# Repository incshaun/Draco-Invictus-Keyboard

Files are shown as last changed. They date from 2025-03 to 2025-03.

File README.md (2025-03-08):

# Draco-Invictus-Keyboard
Converts wired keyboards into bluetooth keyboards

This project contains the software and hardware schematics for a device that allows older PS/2 style keyboards to appear as a bluetooth keyboard. The board uses an ESP32 system-on-chip microcontroller to provide the processing and bluetooth functionality, and requires some level converters to manage the 3.3V required by the ESP32 and 5V required by the PS/2 keyboard.

The software is largely derived from:
* https://github.com/T-vK/ESP32-BLE-Keyboard: for the bluetooth functionality.
* https://github.com/techpaul/PS2KeyAdvanced: for the PS/2 keyboard handling.
* https://github.com/ab0tj/PS2KeyAdvanced-Pico: for some fixes to PS/2 keyboard handling using ESP32
The licenses from these repositories applies to the corresponding code in this repository.

# Software

The software can be compiled and installed using the arduino IDE configured to support an ESP32 Dev Module.

The current version handles the standard keys, as well as capslock and numlock. Additional multimedia keys are not currently supported.

# Hardware

View of the completed board

Notes:
* Power to the unit is supplied using an USB connector. A powerbank is a suitable power source, and allows the keyboard to be portable.
* The ESP32 module is attached to an adapter board (e.g., https://www.komputer.de/zen/index.php?main_page=product_info&products_id=422). This provides buttons to reset and flash the software onto the chip. Note that pull-up resistors on the EN and IO0 lines are required and may not be present on the adapter board. Replacements ($10 \mathsf{k\Omega}$) are included in the schematic and board layout.
* External connector J1 is provided to attached an FTDI FT232RL USB Serial Converter module (e.g., https://littlebirdelectronics.com.au/products/ftdi-ft232rl-usb-to-ttl-serial-converter-adapter-module-5v-and-3-3v). Make sure that this is connected the right way around (GND pin should connect to the ground line), and that the voltage level is set to 3.3 V using the jumper on the board. This module can be removed once the software has been transferred.

The circuit diagram schematic:

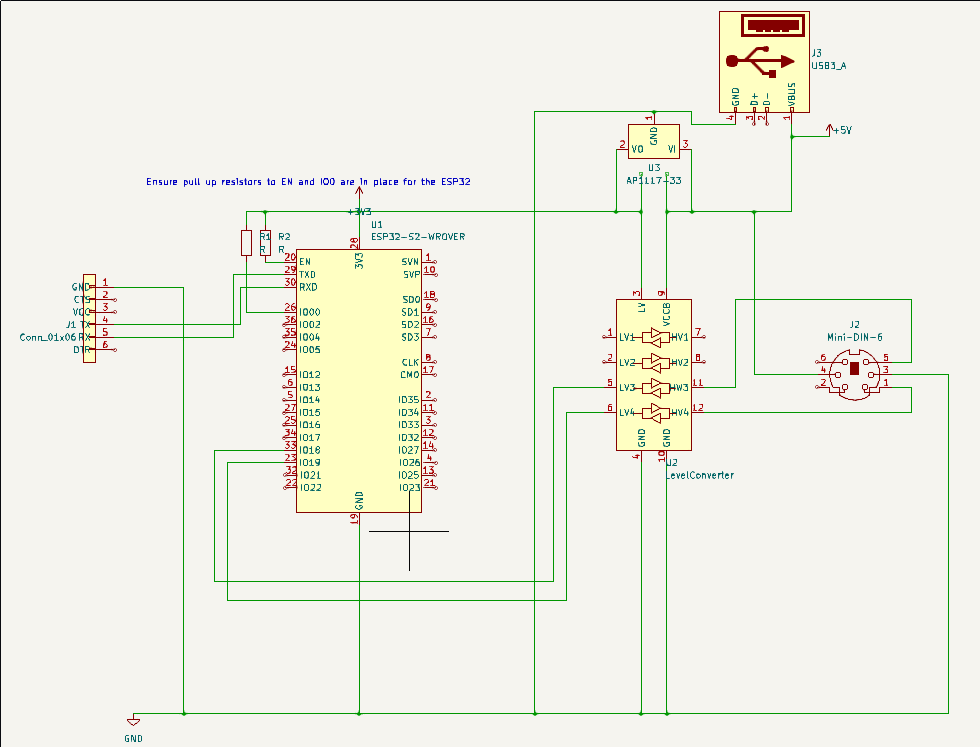
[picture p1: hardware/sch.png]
Schematic


The circuit board layout:

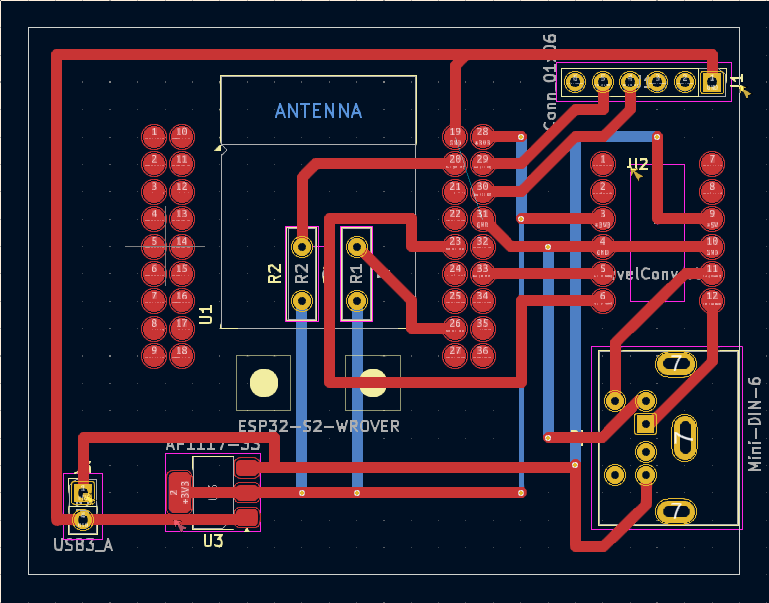
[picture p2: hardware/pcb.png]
Circuit board layout


## Views of an assembled board

Top:

Top View

Bottom (flipped to correspond with circuit layout):

Bottom View

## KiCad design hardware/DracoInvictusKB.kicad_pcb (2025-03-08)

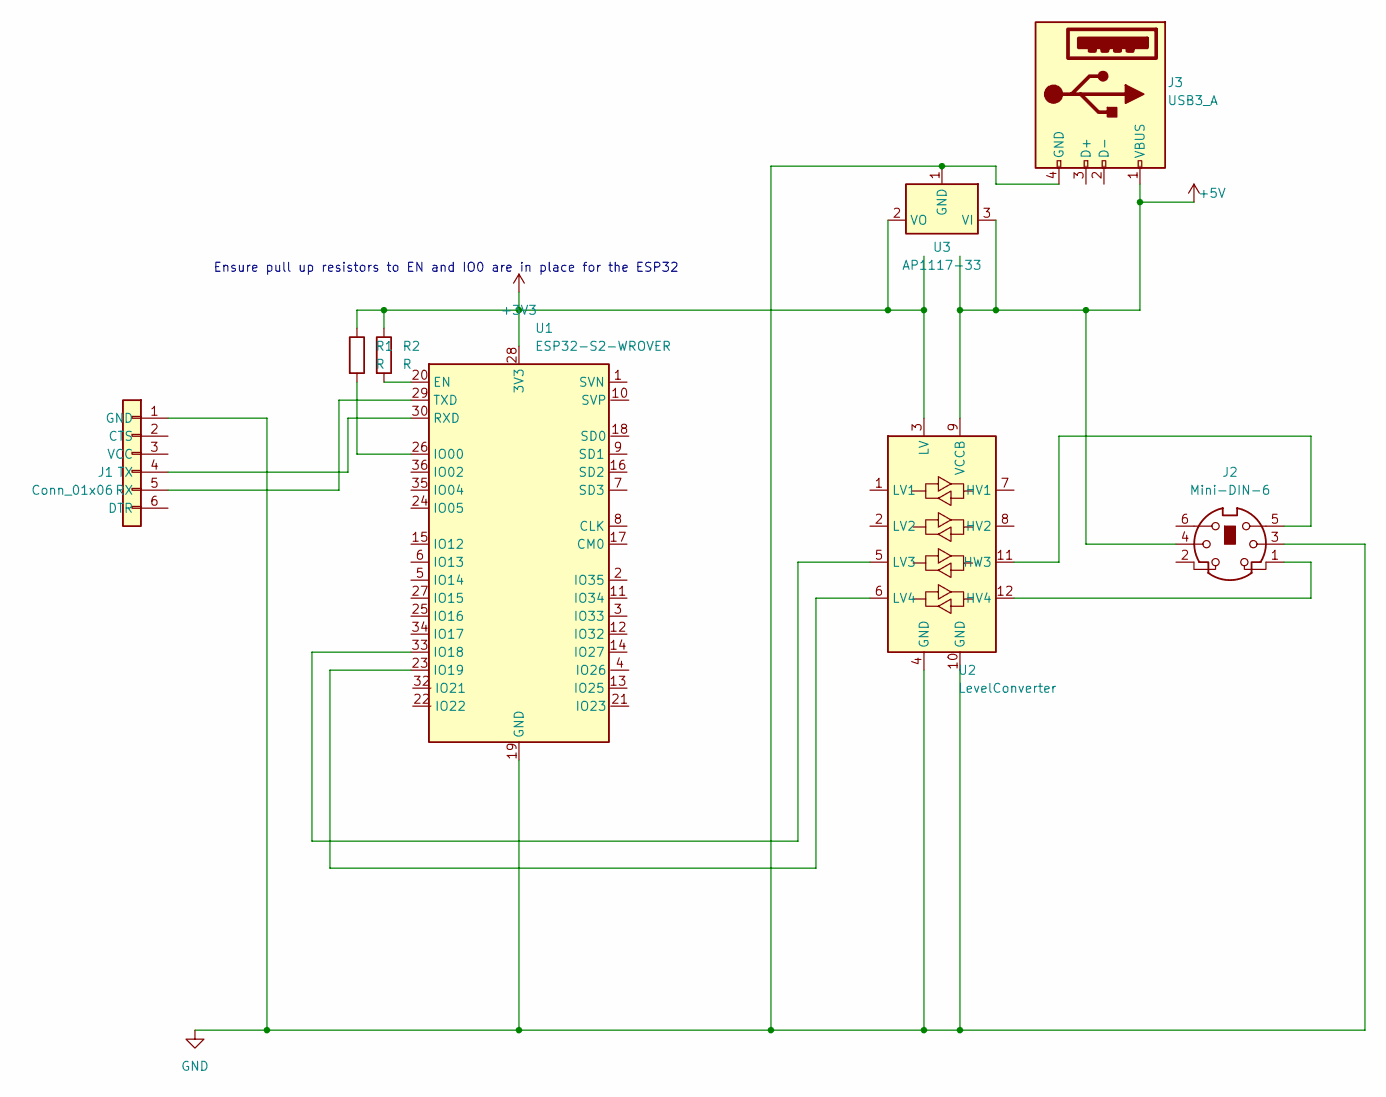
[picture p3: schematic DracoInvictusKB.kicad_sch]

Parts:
J1: Conn_01x06; PinHeader_1x06_P2.54mm_Vertical
J2: Mini-DIN-6; Connector_Mini-DIN_Female_6Pin_2rows
J3: USB3_A; PinHeader_1x02_P2.54mm_Vertical
R1, R2: R; R_Box_L8.4mm_W2.5mm_P5.08mm
U1: ESP32-S2-WROVER
U2: LevelConverter
U3: AP1117-33; SOT-223-3_TabPin2

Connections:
+3V3: R1.1, R2.1, U1.28 (3V3), U2.3 (LV), U3.2 (VO)
+5V: J2.4, J3.1 (VBUS), U2.9 (VCCB), U3.3 (VI)
GND: J1.1 (GND), J2.3, J3.4 (GND), U1.19 (GND), U1.31 (GND), U2.4 (GND), U2.10 (GND), U3.1 (GND)
unnamed: J1.5 (RX), U1.29 (TXD)
unnamed: J1.4 (TX), U1.30 (RXD)
unnamed: R2.2, U1.20 (EN)
unnamed: R1.2, U1.26 (IO00)
unnamed: U1.33 (IO18), U2.5 (LV3)
unnamed: U1.23 (IO19), U2.6 (LV4)
unnamed: J2.1, U2.12 (HV4)
unnamed: J2.5, U2.11 (HW3)

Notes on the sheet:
Ensure pull up resistors to EN and IO0 are in place for the ESP32

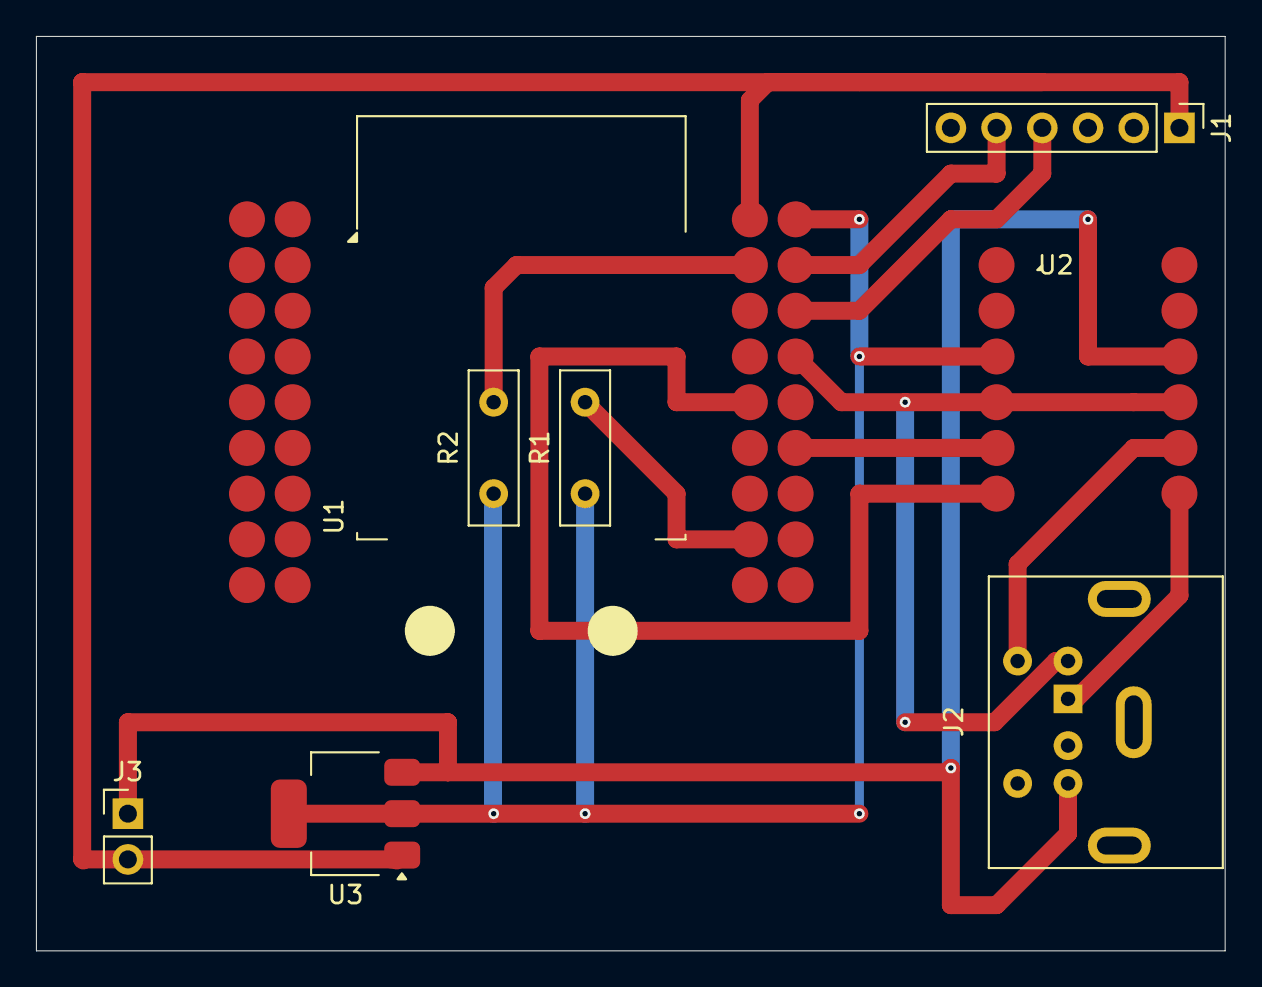
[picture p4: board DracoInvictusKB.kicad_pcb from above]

Board: 2 copper layers, 66.0 x 50.8 mm, 8 parts (0 on the bottom side), 11 nets.

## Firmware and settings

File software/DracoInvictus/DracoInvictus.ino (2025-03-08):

/**
 * This example turns the ESP32 into a Bluetooth LE keyboard that writes the words, presses Enter, presses a media key and then Ctrl+Alt+Delete
 */
#include "BleKeyboard.h"

BleKeyboard bleKeyboard("DracoInvictusKB");

#include "PS2KeyAdvanced.h"

#define DATAPIN 19
#define IRQPIN 18

uint16_t c;

PS2KeyAdvanced keyboard;


void setup() {
  Serial.begin(115200);

  keyboard.begin(DATAPIN, IRQPIN);
  Serial.println("PS2 Advanced Key Simple Test:");


  Serial.println("Starting BLE work!");
  bleKeyboard.begin();
}

void loop() {
  //  Serial.println ("Still alive");

  if (keyboard.available()) {
    // read the next key
    c = keyboard.read();
    if (c > 0) {
      Serial.print("Value ");
      Serial.print(c, HEX);
      Serial.print(" - Status Bits ");
      Serial.print(c >> 8, HEX);
      Serial.print("  Code ");
      Serial.println(c & 0xFF, HEX);


      if (bleKeyboard.isConnected()) {
        Serial.println("Sending");
        uint16_t key = c & 0xFF;

        switch (key) {
          case PS2_KEY_SPACE: key = ' '; break;
          case PS2_KEY_UP_ARROW: key = KEY_UP_ARROW; break;
          case PS2_KEY_DN_ARROW: key = KEY_DOWN_ARROW; break;
          case PS2_KEY_L_ARROW: key = KEY_LEFT_ARROW; break;
          case PS2_KEY_R_ARROW: key = KEY_RIGHT_ARROW; break;
          case PS2_KEY_BS: key = KEY_BACKSPACE; break;
          case PS2_KEY_TAB: key = KEY_TAB; break;
          case PS2_KEY_ENTER: key = KEY_RETURN; break;
          case PS2_KEY_ESC: key = KEY_ESC; break;
          case PS2_KEY_INSERT: key = KEY_INSERT; break;
          case PS2_KEY_PRTSCR: key = KEY_PRTSC; break;
          case PS2_KEY_DELETE: key = KEY_DELETE; break;
          case PS2_KEY_PGUP: key = KEY_PAGE_UP; break;
          case PS2_KEY_PGDN: key = KEY_PAGE_DOWN; break;
          case PS2_KEY_HOME: key = KEY_HOME; break;
          case PS2_KEY_END: key = KEY_END; break;

          case PS2_KEY_KP0: key = KEY_NUM_0; break;
          case PS2_KEY_KP1: key = KEY_NUM_1; break;
          case PS2_KEY_KP2: key = KEY_NUM_2; break;
          case PS2_KEY_KP3: key = KEY_NUM_3; break;
          case PS2_KEY_KP4: key = KEY_NUM_4; break;
          case PS2_KEY_KP5: key = KEY_NUM_5; break;
          case PS2_KEY_KP6: key = KEY_NUM_6; break;
          case PS2_KEY_KP7: key = KEY_NUM_7; break;
          case PS2_KEY_KP8: key = KEY_NUM_8; break;
          case PS2_KEY_KP9: key = KEY_NUM_9; break;
          case PS2_KEY_KP_DOT: key = KEY_NUM_PERIOD; break;
          case PS2_KEY_KP_ENTER: key = KEY_NUM_ENTER; break;
          case PS2_KEY_KP_PLUS: key = KEY_NUM_PLUS; break;
          case PS2_KEY_KP_MINUS: key = KEY_NUM_MINUS; break;
          case PS2_KEY_KP_TIMES: key = KEY_NUM_ASTERISK; break;
          case PS2_KEY_KP_DIV: key = KEY_NUM_SLASH; break;
          case PS2_KEY_KP_EQUAL: key = '='; break;
          case PS2_KEY_KP_COMMA: key = ','; break;

          case PS2_KEY_APOS: key = '\''; break;
          case PS2_KEY_COMMA: key = ','; break;
          case PS2_KEY_MINUS: key = '-'; break;
          case PS2_KEY_DOT: key = '.'; break;
          case PS2_KEY_DIV: key = '/'; break;
          case PS2_KEY_SINGLE: key = '`'; break;
          case PS2_KEY_SEMI: key = ';'; break;
          case PS2_KEY_BACK: key = '\\'; break;
          case PS2_KEY_OPEN_SQ: key = '['; break;
          case PS2_KEY_CLOSE_SQ: key = ']'; break;
          case PS2_KEY_EQUAL: key = '='; break;

          case PS2_KEY_F1: key = KEY_F1; break;
          case PS2_KEY_F2: key = KEY_F2; break;
          case PS2_KEY_F3: key = KEY_F3; break;
          case PS2_KEY_F4: key = KEY_F4; break;
          case PS2_KEY_F5: key = KEY_F5; break;
          case PS2_KEY_F6: key = KEY_F6; break;
          case PS2_KEY_F7: key = KEY_F7; break;
          case PS2_KEY_F8: key = KEY_F8; break;
          case PS2_KEY_F9: key = KEY_F9; break;
          case PS2_KEY_F10: key = KEY_F10; break;
          case PS2_KEY_F11: key = KEY_F11; break;
          case PS2_KEY_F12: key = KEY_F12; break;
          case PS2_KEY_F13: key = KEY_F13; break;
          case PS2_KEY_F14: key = KEY_F14; break;
          case PS2_KEY_F15: key = KEY_F15; break;
          case PS2_KEY_F16: key = KEY_F16; break;
          case PS2_KEY_F17: key = KEY_F17; break;
          case PS2_KEY_F18: key = KEY_F18; break;
          case PS2_KEY_F19: key = KEY_F19; break;
          case PS2_KEY_F20: key = KEY_F20; break;
          case PS2_KEY_F21: key = KEY_F21; break;
          case PS2_KEY_F22: key = KEY_F22; break;
          case PS2_KEY_F23: key = KEY_F23; break;
          case PS2_KEY_F24:
            key = KEY_F24;
            break;

          case PS2_KEY_NUM: key = KEY_NUM_LOCK; break;
          case PS2_KEY_SCROLL: key = KEY_SCROLL_LOCK; break;
          case PS2_KEY_CAPS:
            key = KEY_CAPS_LOCK;
            break;
            //          case PS2_KEY_PAUSE : key = KEY_; break;
          case PS2_KEY_L_SHIFT: key = KEY_LEFT_SHIFT; break;
          case PS2_KEY_R_SHIFT: key = KEY_RIGHT_SHIFT; break;
          case PS2_KEY_L_CTRL: key = KEY_LEFT_CTRL; break;
          case PS2_KEY_R_CTRL: key = KEY_RIGHT_CTRL; break;
          case PS2_KEY_L_ALT: key = KEY_LEFT_ALT; break;
          case PS2_KEY_R_ALT: key = KEY_RIGHT_ALT; break;
          case PS2_KEY_L_GUI: key = KEY_LEFT_GUI; break;
          case PS2_KEY_R_GUI:
            key = KEY_RIGHT_GUI;
            break;
            //          case PS2_KEY_MENU : key = KEY_; break;
            //          case PS2_KEY_BREAK : key = KEY_; break;
        }
        if ((key >= 'A') && (key <= 'Z')) {
          key = key - 'A' + 'a';
        }
        if (key != 0xFA) {
          if ((key == KEY_CAPS_LOCK) || (key == KEY_NUM_LOCK) || (key == KEY_SCROLL_LOCK))  // toggle, so double press/release rather than press or release.
          {
            bleKeyboard.press(key);
            bleKeyboard.release(key);
          } else {
            if (c & PS2_BREAK)  // release
            {
              bleKeyboard.release(key);
            } else {
              bleKeyboard.press(key);
            }
          }
        }
      }
    }
  }


  //  if (bleKeyboard.isConnected()) {
  //    Serial.println("Sending 'Hello world'...");
  //  bleKeyboard.print("Hello world");

  //   delay(1000);

  // Serial.println("Sending Enter key...");
  //   bleKeyboard.write(KEY_RETURN);

  //   delay(1000);

  //   Serial.println("Sending Play/Pause media key...");
  //   bleKeyboard.write(KEY_MEDIA_PLAY_PAUSE);

  //   delay(1000);

  //  Serial.println("Sending Ctrl+Alt+Delete...");
  //  bleKeyboard.press(KEY_LEFT_CTRL);
  //  bleKeyboard.press(KEY_LEFT_ALT);
  //  bleKeyboard.press(KEY_DELETE);
  //  delay(100);
  //  bleKeyboard.releaseAll();
  //  }

  //  Serial.println("Waiting 5 seconds...");
  // delay(5000);
}

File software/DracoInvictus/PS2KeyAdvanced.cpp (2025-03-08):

/* Version V1.0.9
  PS2KeyAdvanced.cpp - PS2KeyAdvanced library
  Copyright (c) 2007 Free Software Foundation.  All right reserved.
  Written by Paul Carpenter, PC Services <sales@pcserviceselectronics.co.uk>
  Created September 2014
  Updated January 2016 - Paul Carpenter - add tested on Due and tidy ups for V1.5 Library Management
    January 2020   Fix typos, correct keyboard reset status improve library.properties 
		   and additional platform handling and some documentation
    March 2020  Add SAMD1 as recognised support as has been tested by user
                Improve different architecture handling
    November 2020 Add support for STM32 from user Hiabuto-de
                  Tested on STM32Duino-Framework and PlatformIO on STM32F103C8T6 and an IBM Model M
    July 2021   Add workaround for ESP32 issue with Silicon (hardware) from user submissions

  IMPORTANT WARNING
 
    If using a DUE or similar board with 3V3 I/O you MUST put a level translator 
    like a Texas Instruments TXS0102 or FET circuit as the signals are 
    Bi-directional (signals transmitted from both ends on same wire).
 
    Failure to do so may damage your Arduino Due or similar board.

  Test History
    September 2014 Uno and Mega 2560 September 2014 using Arduino V1.6.0
    January 2016   Uno, Mega 2560 and Due using Arduino 1.6.7 and Due Board 
                    Manager V1.6.6
                    

  Assumption - Only ONE keyboard added to one Arduino
             - No stream support

  This is for a LATIN style keyboard using Scan code set 2. See various
  websites on what different scan code sets use. Scan Code Set 2 is the
  default scan code set for PS2 keyboards on power up.

  Fully featured PS2 keyboard library to provide
    All keys as a keycode (A-Z and 0-9 as ASCII equivalents)
    All function and movement keys supported even multi-lingual
    Parity checking of data sent/received on receive request keyboard resend
    Resends data when needed handles keyboard protocol for RESEND and ECHO
    Functions for get and set of
        Scancode set in use READ only
        LED and LOCK control
        ReadID
        Reset keyboard
        Send ECHO
        Handles NUM, _CAPS and SCROLL lock keys to LEDs
        Handles NUM/SCROLL internally

  Returns an uint16_t containing
        Make/Break status
        CAPS status
        SHIFT, CTRL, ALT, ALT GR, GUI keys
        Flag for function key not a displayable/printable character
        8 bit key code

    Code Ranges(bottom byte of uint16_t) see PS2KeyAdvanced.h for details
        0       invalid/error
        1-1F    Functions (_CAPS, _SHIFT, _ALT, Enter, DEL... )
        1A-1F   Functions with ASCII control code
                    (DEL, BS, TAB, ESC, ENTER, SPACE)
        20-60   Printable characters noting
                    0-9 = 0x30 to 0x39 as ASCII
                    A to Z = 0x41 to 0x5A as upper case ASCII type codes
                    8B Extra European key
        61-A0   Function keys and other special keys (plus F2 and F1 less 8B)
                    61-78 F1 to F24
                    79-8A Multimedia
                    8C-8E ACPI power
                    91-A0 and F2 and F1 - Special multilingual
        A8-FF   Keyboard communications commands (note F2 and F1 are special
                codes for special multi-lingual keyboards)

    By using these ranges it is possible to perform detection of any key and do
    easy translation to ASCII/UTF-8 avoiding keys that do not have a valid code.

    Top Byte is 8 bits denoting as follows with defines for bit code

        Define name bit     description
        PS2_BREAK   15      1 = Break key code
                   (MSB)    0 = Make Key code
        PS2_SHIFT   14      1 = Shift key pressed as well (either side)
                            0 = NO shift key
        PS2_CTRL    13      1 = Ctrl key pressed as well (either side)
                            0 = NO Ctrl key
        PS2_CAPS    12      1 = Caps Lock ON
                            0 = Caps lock OFF
        PS2_ALT     11      1 = Left Alt key pressed as well
                            0 = NO Left Alt key
        PS2_ALT_GR  10      1 = Right Alt (Alt GR) key pressed as well
                            0 = NO Right Alt key
        PS2_GUI      9      1 = GUI key pressed as well (either)
                            0 = NO GUI key
        PS2_FUNCTION 8      1 = FUNCTION key non-printable character (plus space, tab, enter)
                            0 = standard character key

  Error Codes
     Most functions return 0 or 0xFFFF as error, other codes to note and
     handle appropriately value in bottom byte
        0xAA   keyboard has reset and passed power up tests
               will happen if keyboard plugged in after code start
        0xFC   Keyboard General error or power up fail

  It is responsibility of your programme to deal with converting special cases
  like <_CTRL>+<ENTER> sends a special code to something else. A better method
  is to use PS2KeyMap library and add your own table to that library. If you
  wish to do that make a NEW library called SOMETHING different NOT a variant
  or revision of this one, as you are changing base functionality

  See PS2KeyCode.h for codes from the keyboard this library uses to decode.
  (may disappear in updates do not rely on this file or definitions)

  See PS2KeyAvanced.h for returned definitions of Keys and accessible
  definitions

  See PS2KeyMap.h for tables currently supported

  To get the key as ASCII/UTF-8 single byte character conversion requires use
  of PS2KeyMap library AS WELL.

  This library is free software; you can redistribute it and/or
  modify it under the terms of the GNU Lesser General Public
  License as published by the Free Software Foundation; either
  version 2.1 of the License, or (at your option) any later version.

  This library is distributed in the hope that it will be useful,
  but WITHOUT ANY WARRANTY; without even the implied warranty of
  MERCHANTABILITY or FITNESS FOR A PARTICULAR PURPOSE.  See the GNU
  Lesser General Public License for more details.

  You should have received a copy of the GNU Lesser General Public
  License along with this library; if not, write to the Free Software
  Foundation, Inc., 51 Franklin St, Fifth Floor, Boston, MA  02110-1301  USA
*/
#include <Arduino.h>
// Internal headers for library defines/codes/etc
#include "PS2KeyAdvanced.h"
#include "PS2KeyCode.h"
#include "PS2KeyTable.h"


// Private function declarations
void send_bit( void );
void send_now( uint8_t );
int16_t send_next( void );
void ps2_reset( void );
uint8_t decode_key( uint8_t );
void pininput( uint8_t );
void set_lock( );
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

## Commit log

2025-03-08 Added in the kicad files for the circuit board
    [DracoInvictusKB.kicad_pcb, DracoInvictusKB.kicad_sch]
2025-03-08 Included some images showing the physical board
